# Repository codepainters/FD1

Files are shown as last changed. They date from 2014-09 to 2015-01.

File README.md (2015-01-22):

FD-1 MIDI Foot Keyboard Controller
==================================

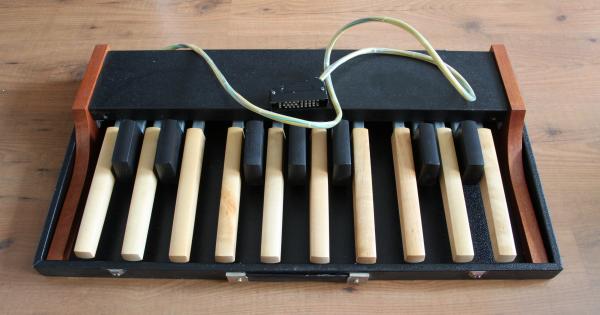
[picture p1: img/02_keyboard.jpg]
 

FD-1 is a simple MIDI Foot (organ) Keyboard Controller project, 
based on LPC1343 Cortex-M3 microcontroller. 

The design features:

 * separate keyboard and controller modules, connected using an HDMI cable 
   (the cheapest multi-wire cable available)

 * a simple control panel with a 7-segment display and a rotary encoder, 
   allowing for changing the MIDI channel, velocity and octave shift on the fly 
   (note: the keyboard used for the project has only a single NO contact per key,
   thus the keyboard can't be dynamic)

 * persistent storage (in Flash) of the settings

 * USB port, at the moment used for firmware flashing only, there's a plan to 
   include MIDI-over-USB implementation later

 * switching-mode voltage regulator - controller can be powered from 6-12V DC 
   (usual 9V DC power supply recommended, as used for guitar stomp-boxes)

The project repository contains:

 * `hardware` - schematics and PCBs
 * `firmware` - all the C code
 * `datasheets` - datasheets and manuals used during the development

Dedicated project page (with pictures) to follow soon.

All the project files are licensed under Modified BSD License (see LICENSE.txt).

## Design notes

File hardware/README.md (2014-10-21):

FD-1 Hardware
============

This directory contains all the schematics and PCBs in DipTrace format. You can download a free version of DipTrace from [http://diptrace.com/download-diptrace/](here).

Also:

 * `gerbers` - Gerber and Excellon files for the PCBs

 * `pdfs` - all the schematics in PDFs, for those not willing
   to install a commercial EDA tool

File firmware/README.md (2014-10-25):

FD-1 Firmware
============

This directory contains the controller's firmware source code, written in plain C. A few files in `lpc1xxx` directory (namely: linker script, header file with register definitions, startup routine) were "borrowed" from [LPC1343CodeBase](http://www.microbuilder.eu/Projects/LPC1343ReferenceDesign/LPC1343CodeBase.aspx) project.

Toolkit
---------

To build the firmware you need a GCC cross-toolchain for ARM. The toolkit available [here](https://launchpad.net/gcc-arm-embedded/+download) was used for development, but any recent GCC toolkit will do. Note: builidng is possible on Mac and Linux, **no Windows support**. Sorry!

The project's makefile expects the `PATH` environment variable to include toolkit's `bin` directory, so `arm-none-eabi-gcc` can be executed without giving the full path.

Other dependencies
----------------------------

You also need:

 * `GNU make` - v3.81 used for development
 * `python` - for the script calculating the firmware checksum

Building
-----------

It's enough to execute `make` in this directory. You should get the following files:

 * `firmware.elf` - to be used e.g. for debugging or flashing with GDB
 * `firmware.bin` - binary firmware (with correct checksum, as needed by the LPC1343 bootloader)

Flashing
-----------

The easiest way to flash the firmware is to use LPC1343's built-in bootloader's feature - programming via USB mass storage (disk) device. Follow these steps:

 * short the `J6` pins (next to `JTAG` socket) with a jumper
 * connect the USB cable - the device should enumerate as a mass-storage device
 * copy the `firmware.bin` file onto this virtual drive
 * unmount the device
 * disconnect USB cable, remove the jumper

That's it!

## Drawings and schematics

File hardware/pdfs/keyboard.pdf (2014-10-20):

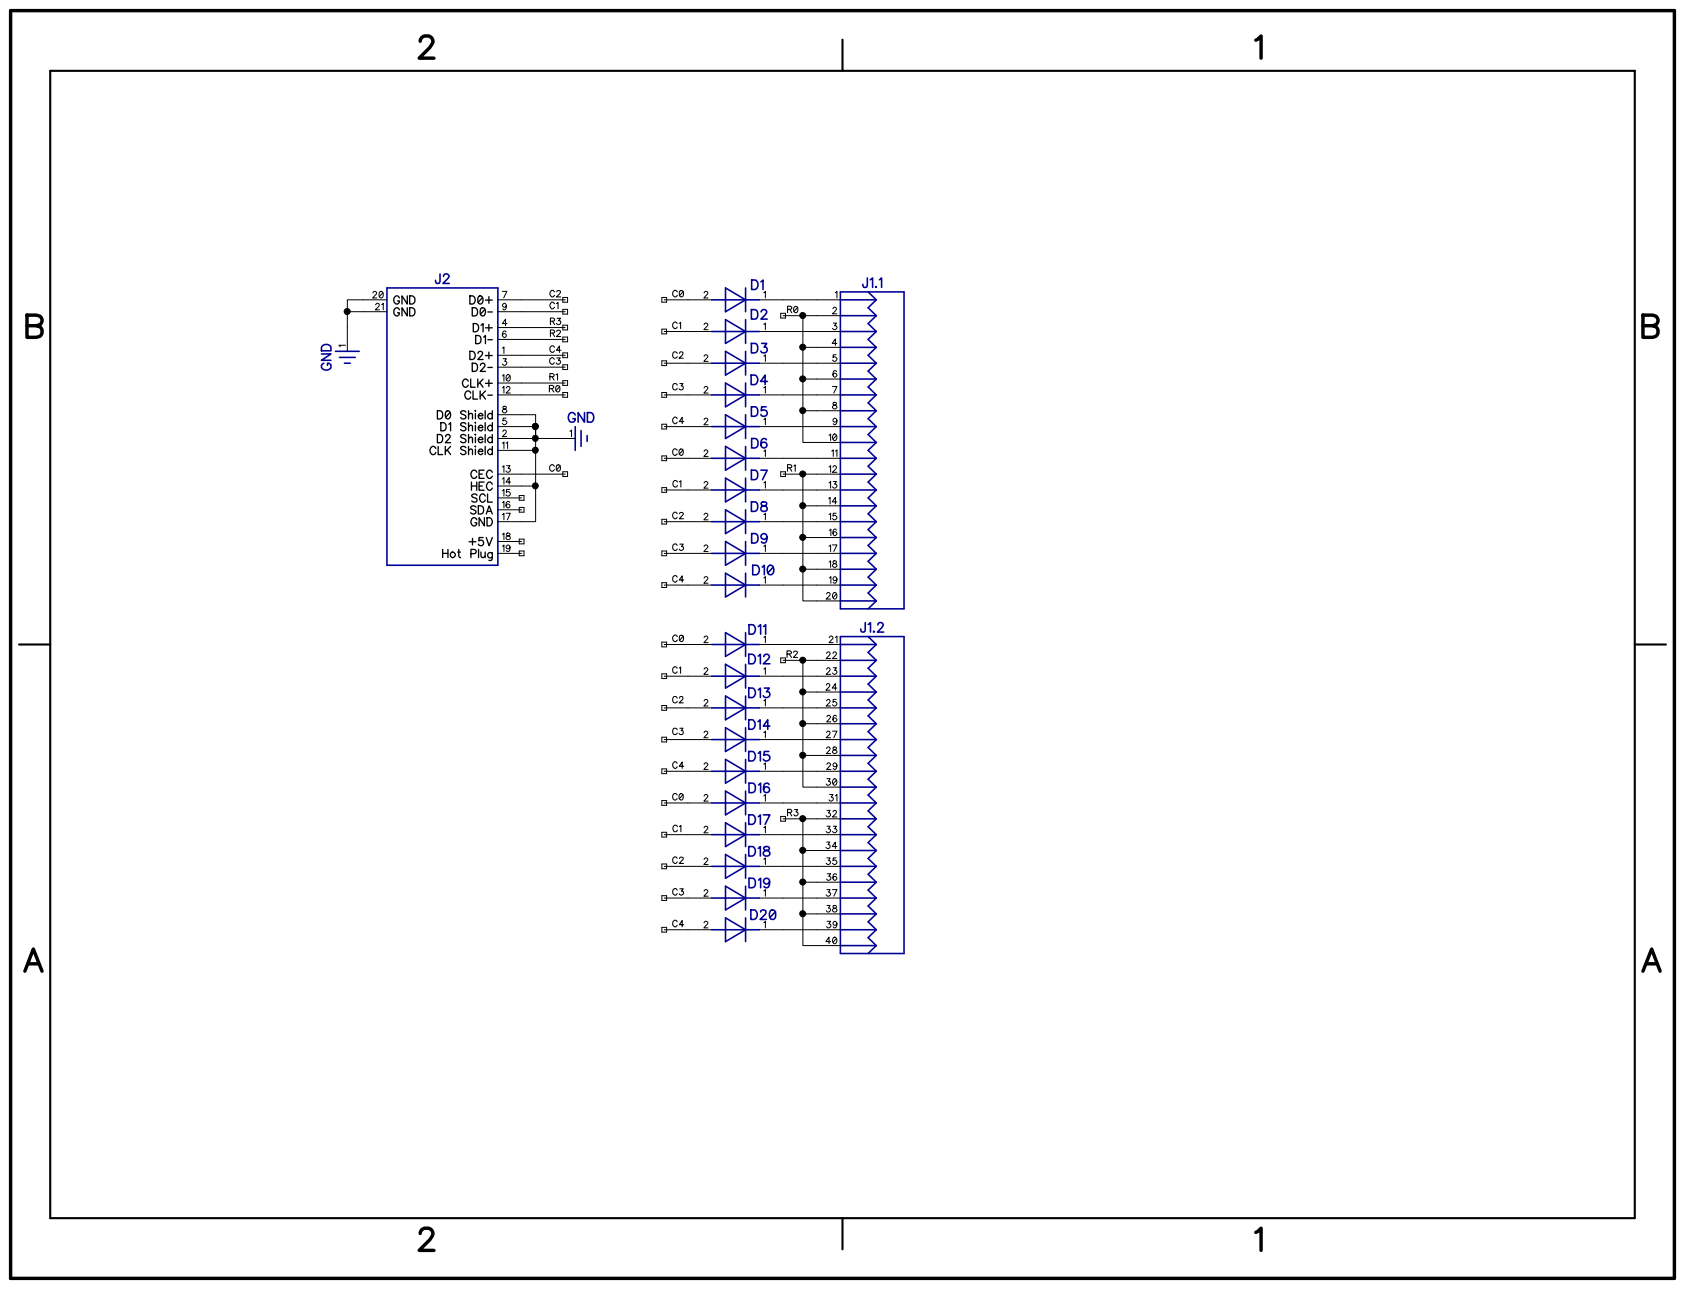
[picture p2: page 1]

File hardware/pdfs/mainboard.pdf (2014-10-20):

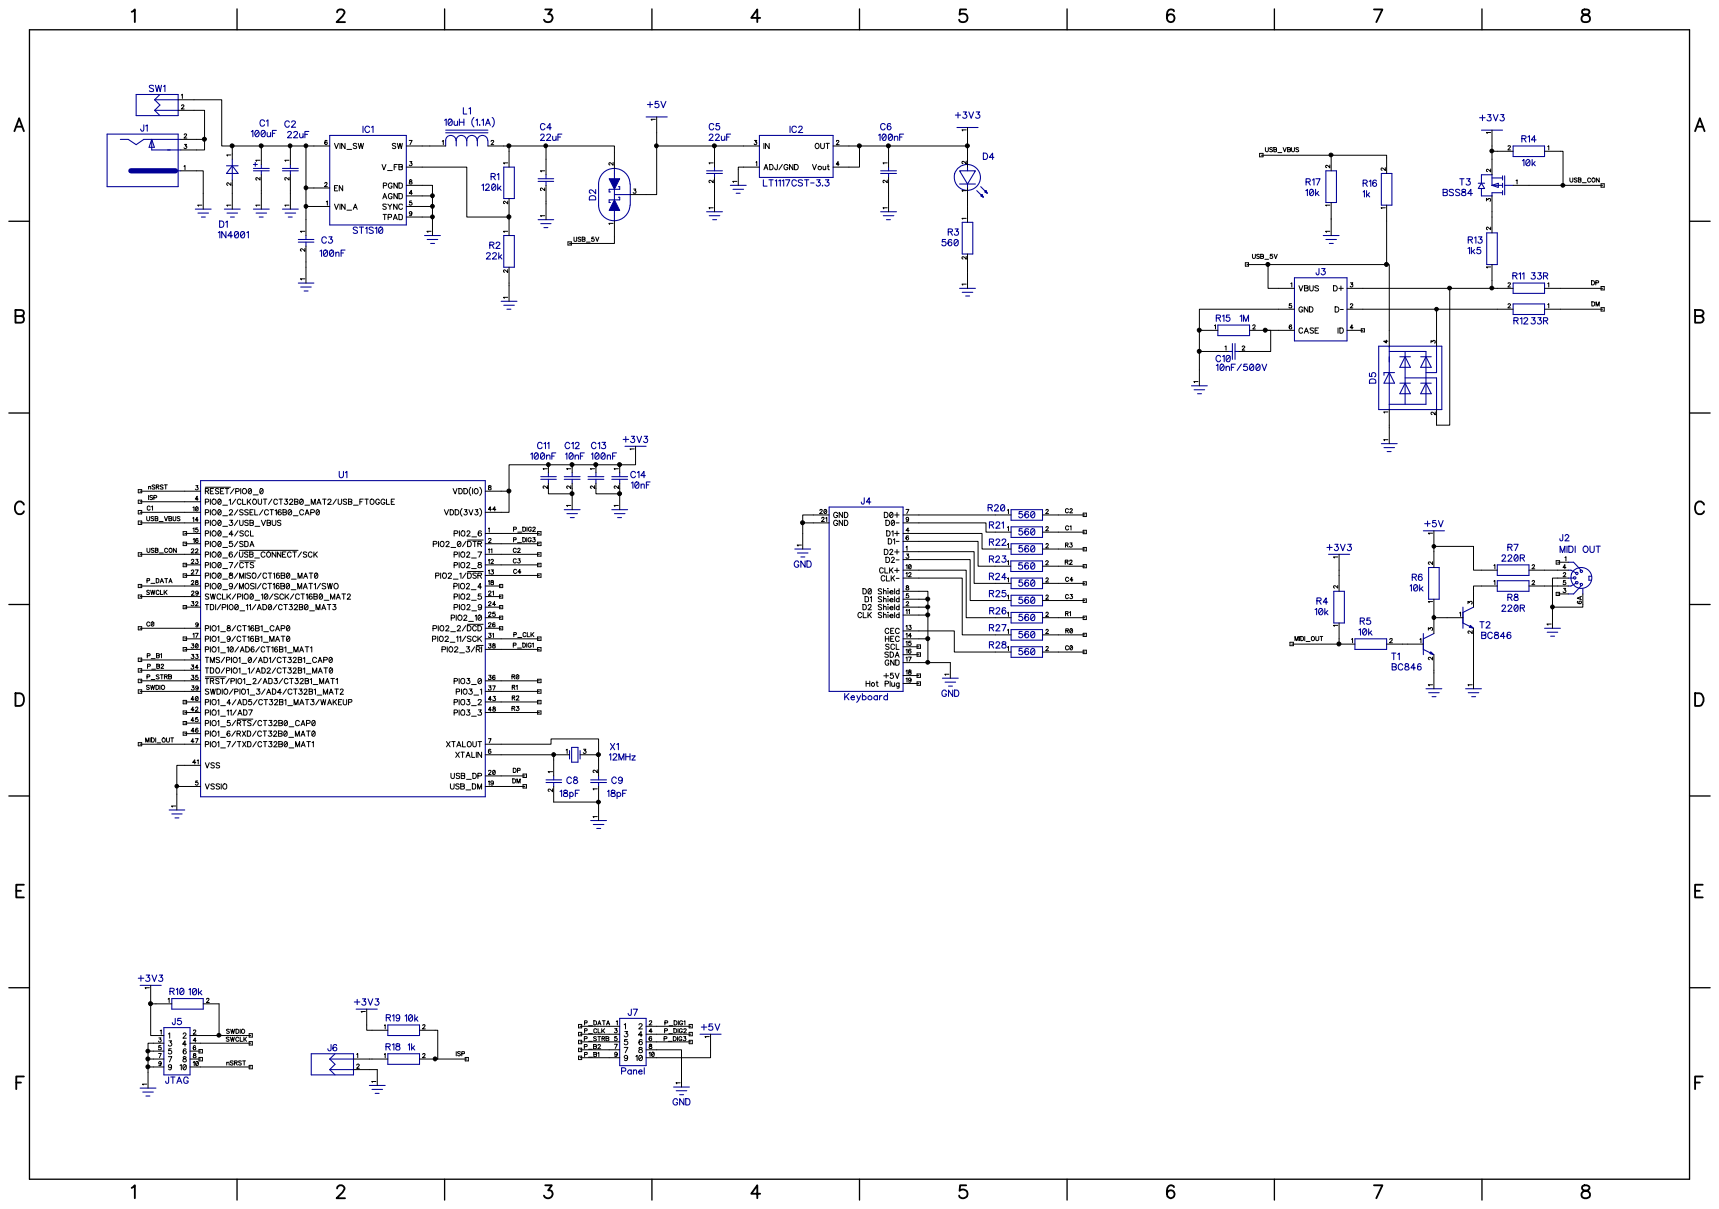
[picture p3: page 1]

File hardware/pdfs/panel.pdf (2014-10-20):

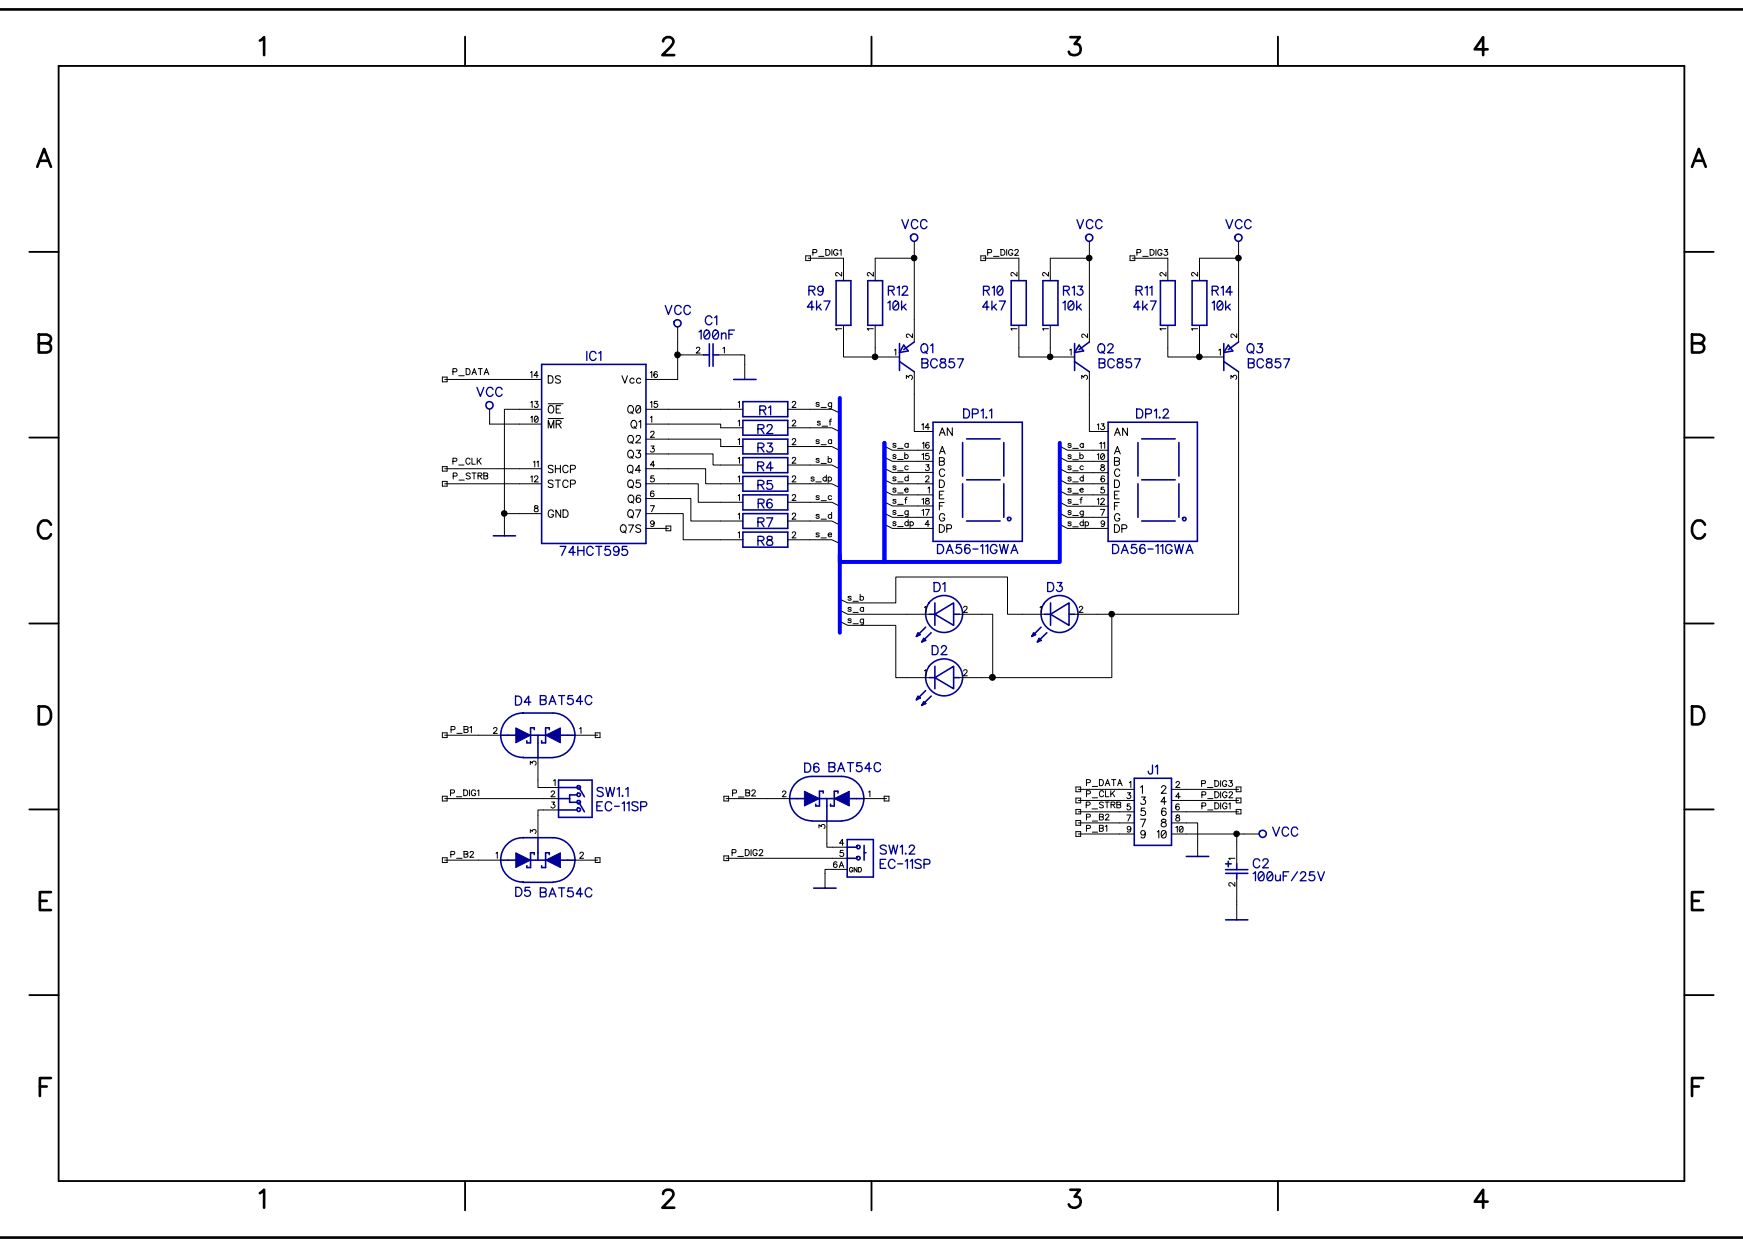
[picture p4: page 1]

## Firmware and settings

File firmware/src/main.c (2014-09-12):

/**
 * Copyright (c) 2014, Przemyslaw Wegrzyn <pwegrzyn@codepainters.com>
 * All rights reserved.
 *
 * This file is distributed under the Modified BSD License.
 * See LICENSE.txt for details.
 */

#include "lpc134x.h"

#include "gpio_pin.h"
#include "panel.h"
#include "keyboard.h"
#include "midi.h"
#include "settings_store.h"

#define USE_DEBUG_PIN 1

#if USE_DEBUG_PIN
static const GpioPin_t DEBUG_PIN = { &IOCON_PIO0_1, 0, 1, IOCON_PIO0_1_FUNC_GPIO | IOCON_PIO0_1_HYS_DISABLE | IOCON_PIO0_1_MODE_INACTIVE };
#define SET_DEBUG_PIN(v) do { GpioPin_SetState(&DEBUG_PIN, (v)); } while(0)
#else
#define SET_DEBUG_PIN(v)
#endif

#define TIMER16_CCLK_100US      ((CFG_CPU_CCLK/SCB_SYSAHBCLKDIV) / 10000)

static void cpuSetup();

int main() {
    cpuSetup();

#if USE_DEBUG_PIN
    GpioPin_ConfigureOut(&DEBUG_PIN, 0);
#endif

    SettingsStore_Init();

    // intiailize sub-modules
    MIDI_Init();
    Panel_Init();

    // FIXME: panel must be configured first at the moment,
    // as LPC1343CodeBase SPI driver reconfigures PIO0.2
    Keyboard_Init();

    // enable TMR16B0 clock
    SCB_SYSAHBCLKCTRL |= SCB_SYSAHBCLKCTRL_CT16B0;

    // configure TMR16B0 to kick at 10kHz
    TMR_TMR16B0MR0 = TIMER16_CCLK_100US;
    TMR_TMR16B0MCR = TMR_TMR16B0MCR_MR0_INT_ENABLED | TMR_TMR16B0MCR_MR0_RESET_ENABLED;

    // Enable the TIMER0 interrupt, end eventually enable the timer itself
    NVIC_EnableIRQ(TIMER_16_0_IRQn);
    TMR_TMR16B0TCR = TMR_TMR16B0TCR_COUNTERENABLE_ENABLED;

    // keyboard and panel handling is performed in the timer interrupt context
    // all we need to do in the main code is to send any pendind MIDI data
    // and go to sleep until next interrupt

    while (1) {
        MIDI_SendQueued();

        // Wait For Interrupt
        __asm volatile ("wfi");
    }

    return 0;
}

void TIMER16_0_IRQHandler(void) {
    // Clear the interrupt flag
    TMR_TMR16B0IR = TMR_TMR16B0IR_MR0;

    SET_DEBUG_PIN(1);

    Keyboard_TimerTick();

    // Note: encoder needs such a high rate (10kHz / 3) to work reliably!
    Panel_TimerTick();

    SET_DEBUG_PIN(0);
}

static void cpuSetup()
{
    uint32_t i;

    // Power up system oscillator
    SCB_PDRUNCFG &= ~(SCB_PDRUNCFG_SYSOSC_MASK);

    // Setup the crystal input (bypass disabled, 1-20MHz crystal)
    SCB_SYSOSCCTRL = (SCB_SYSOSCCTRL_BYPASS_DISABLED | SCB_SYSOSCCTRL_FREQRANGE_1TO20MHZ);

    for (i = 0; i < 200; i++) {
        __asm volatile ("NOP");
    }

    // external crystal as PLL clock source
    SCB_PLLCLKSEL = SCB_CLKSEL_SOURCE_MAINOSC;
    SCB_PLLCLKUEN = SCB_PLLCLKUEN_UPDATE;
    SCB_PLLCLKUEN = SCB_PLLCLKUEN_DISABLE;
    SCB_PLLCLKUEN = SCB_PLLCLKUEN_UPDATE;

    // wait until the clock is updated
    while (!(SCB_PLLCLKUEN & SCB_PLLCLKUEN_UPDATE));

    // set x6 multiplier, FCCO = 2 * 2 * 72 = 288MHz
    SCB_PLLCTRL = (SCB_PLLCTRL_MSEL_6 | SCB_PLLCTRL_PSEL_2);

    // enable system PLL, wait for lock
    SCB_PDRUNCFG &= ~(SCB_PDRUNCFG_SYSPLL_MASK);
    while (!(SCB_PLLSTAT & SCB_PLLSTAT_LOCK));

    // setup main clock to use PLL output
    SCB_MAINCLKSEL = SCB_MAINCLKSEL_SOURCE_SYSPLLCLKOUT;
    SCB_MAINCLKUEN = SCB_MAINCLKUEN_UPDATE;
    SCB_MAINCLKUEN = SCB_MAINCLKUEN_DISABLE;
    SCB_MAINCLKUEN = SCB_MAINCLKUEN_UPDATE;

    // Wait until the clock is updated
    while (!(SCB_MAINCLKUEN & SCB_MAINCLKUEN_UPDATE));

    // set system AHB clock - div by 1
    SCB_SYSAHBCLKDIV = SCB_SYSAHBCLKDIV_DIV1;

    // enabled IOCON clock for GPIO
    SCB_SYSAHBCLKCTRL |= SCB_SYSAHBCLKCTRL_IOCON;
}

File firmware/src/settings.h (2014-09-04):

/**
 * Copyright (c) 2014, Przemyslaw Wegrzyn <pwegrzyn@codepainters.com>
 * All rights reserved.
 *
 * This file is distributed under the Modified BSD License.
 * See LICENSE.txt for details.
 */

#ifndef __SETTINGS_H__
#define __SETTINGS_H__

#include "lpc134x.h"

#define MIDI_CHANNEL_MIN        (0)
#define MIDI_CHANNEL_MAX        (15)
#define MIDI_CHANNEL_DEFAULT    (0)

#define OCTAVE_SHIFT_MIN        (0)
#define OCTAVE_SHIFT_MAX        (5)
#define OCTAVE_SHIFT_DEFAULT    (2)

#define MIDI_VELOCITY_MIN       (0)
#define MIDI_VELOCITY_MAX       (127)
#define MIDI_VELOCITY_DEFAULT   (127)

/**
 * This structure contains all the user-settable parameters.
 */
typedef struct Settings_tag {

    // MIDI channel to send the messages to [0..15]
    unsigned int midiChannel;

    // octave shift of the keyboard notes
    unsigned int octave;

    // MIDI notes velocity [0..127]
    unsigned int velocity;

} Settings_t;

extern Settings_t settings;

#endif // __SETTINGS_H__

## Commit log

2012-10-24 HDMI socket datasheet
2012-10-26 Keyboard schematic completed, HDMI connector, PCB in progress
2012-10-26 Keyboard PCB routed
2012-10-30 Keyboard PCB updated (diode spacing).
2012-11-11 Keyboard PCB updates
2012-11-13 PIN assignment skeleton
2013-02-24 Started main board schematic
2013-02-26 Added DIN5 schematic symbol
2013-02-27 Added DIN-5 socket datasheet
2013-02-28 DIN5 connector pattern finished
2013-03-22 Added pattern for the LED display
2013-03-22 LED display symbol added for schematics
2013-03-22 Schematic symbol added for the rotary encoder
2013-03-22 Added footprint for rotary encoder
2013-03-22 Fixed pin mapping
2013-03-22 Started fron panel schematic
2013-03-26 Added symbols for 2mm IDC 2x5 connector, VCC/GDN european symbols
2013-03-26 Fixed schematic symbol for LED display
2013-03-26 Front panel schematics - display section completed
2013-03-26 Panel schematic - work in progress
2013-03-26 Added push button symbol, completed panel sch
2013-04-01 Panel schematic - fixed resistor pattern
2014-05-08 Mainboard - schematic sheet border added
2014-05-19 Mainboard schematics continued
2014-05-21 Mainboard - USB/MIDI/power supply done
2014-05-24 One more LP1343 board for reference
2014-06-02 Mainboard footprints updated
2014-06-02 Updated XTAL footprint
2014-06-02 Mainboard PCB started
2014-07-03 Mainboard schematic - minor udpates.
2014-07-03 Mainboard PCB - component layout sketch
2014-07-04 Fixed MIDI / USB sockets positioning
2014-07-04 Moved the board so lower left corner is at (0, 0)
2014-07-04 Third mounting hole.
2014-07-06 Micro-USB socket datasheet
2014-07-07 Symbols - ST1S10 now has a thermal pad pin
2014-07-07 Replaced BAT54C with 2 separate Schottky diodes
2014-07-07 Current routing snapshot
2014-07-08 Fixed diameters, poured bottom GND plane
2014-07-09 Added protection resistors to kbd I/O
2014-07-09 Removed MIDI_IN net from schematic
2014-07-09 USB_VBUS error fixed on PCB
2014-07-09 PCB beta-1 completed
2014-07-09 Gerbers for mainboard v1.0
    [mainboard.drl, mainboard_BoardOutline.gbr, mainboard_Bottom.gbr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]
2014-07-09 Front panel PCB - initial netlist import
2014-07-11 Panel v1.0 with gerbers/excellon
    [panel.drl, panel_BoardOutline.gbr, panel_Bottom.gbr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]
2014-07-11 Fixed pad sizes on the keyboard PCB
2014-07-11 Added missing bototm silk gerber (panel)
    [panel_BottomSilk.gbr]
2014-07-11 Minor edits (silk)
    [keyboard.drl, keyboard_BoardOutline.gbr, keyboard_Bottom.gbr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]
2014-07-11 Added keyboard PCB marking
    [keyboard_BottomSilk.gbr]
2014-07-11 Mainboard sch - fixed power supply polarity
2014-07-11 Mainboard PCB updated (pwr polarity fix)
2014-07-11 Gerbers for the mainboard updated
    [mainboard_Bottom.gbr, mainboard_BottomMask.gbr, mainboard_Top.gbr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]
2014-07-14 Mainboard - added ground plane vias
2014-07-14 Mainboard - updated gerbers
    [mainboard.drl, mainboard_Bottom.gbr, mainboard_Top.gbr]
2014-08-18 One more CLKOUT fix
    [main.c]
2014-08-19 Missing from previous commit.
    [main.c]
2014-08-19 Switched to lpcrc python rewrite.
2014-08-19 Fixed front panel design bug (missing kbd diodes) (missing kbd diodes) (missing kbd diodes) (missing kbd diodes) (missing kbd diodes) (missing kbd diodes) (missing kbd diodes) (missing kbd diodes) (m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
2014-08-19 Cosmetic updates to the schematics
2014-08-19 Display correctly selects digits now, added hex digits defs
    [display.c]
2014-08-19 Display - setting LEDs state now work
2014-08-19 Added buttons module stub
2014-08-19 Buttons - work in progress
2014-08-20 Fixed a problem with column lines not going to logical 0
    [buttons.c, display.c]
2014-08-22 Added encoder support
2014-08-26 Refactored buttons handler.
2014-08-26 iReverted encoder FSM changes, it was messed up.
2014-08-26 Fixed GPIO configuration for panel buttons
2014-08-26 Fixed encoder handling bug in panel.
2014-08-26 Buttons - explicit init of global val.
2014-08-26 Buttons handler fixed.
2014-08-26 Midi module integrated (missing interrupt disabling)
    [keyboard.c, main.c, midi.c]
2014-08-26 MIDI FIFO code made interrupt-safe
2014-08-26 Added debug pin macros, let's measure something
2014-08-26 Fixed a timing problem in matrix keyboard code
    [keyboard.c]
2014-08-26 Dead keys problem resolved
    [main.c]
2014-08-26 Ketyboard settings fixed for actual keyboard
    [keyboard.c]
2014-08-27 Datasheet for the power supply socket
2014-09-01 Panel schematic - added pull-up resistors
2014-09-01 Panel - pull-ups added to PCB
2014-09-02 Buttons module switched to GpioPin
2014-09-02 Display no longer uses LPC1343CodeBase SSP
    [display.c]
2014-09-02 Little fix, configure digit pins as IN initially
    [display.c]
2014-09-02 Buttons module cleaned, no longer called from display.c directly
    [buttons.c, display.c]
2014-09-02 Switched to own LPC1343CodeBase copy
2014-09-02 Fixing invalid edit - MIDI needs display.h for blinking
    [midi.c]
2014-09-03 Fixed the display code, broken after rework
    [display.c]
2014-09-04 Removinf obsolete pin assignment file
2014-09-04 Converted consts to macros, there was something wrong about it
    [main.c]
2014-09-11 Mainboard PCB drill fixes
2014-09-11 Updated mainboard gerbers
    [mainboard.drl, mainboard_BoardOutline.gbr, mainboard_Bottom.gbr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]
2014-09-12 Got rid of LPC1343CodeBase timer stuff
2014-09-12 Got rid of CodeBase UART
2014-10-01 Panel schematic - added 100uF decoupling cap
2014-10-20 Panel PCB updated (added C2 capacitor)
2014-10-20 Keyboard schematic - border
2014-10-20 Schematic PDFs
2014-10-20 Move socket datahseet to the write place
2014-10-20 Mainboard PCB updated (22uF caps changed to 1206)
2014-10-21 New Gerber/Excellon files for mainboard
    [mainboard.drl, mainboard_Bottom.gbr, mainboard_BottomMask.gbr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]
2014-10-21 New panel PCB Gerber/Excellon files
    [panel.drl, panel_BoardOutline.gbr, panel_Bottom.gbr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]
2014-10-21 Panel PCB - top silk cleanup
2014-10-22 Other boards schemtics no longer needed
